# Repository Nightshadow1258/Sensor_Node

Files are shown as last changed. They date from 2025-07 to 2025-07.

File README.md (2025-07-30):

# Sensor Node Version 3.50
This is an intermediate version before I decided to move to a two part design.
I split the MCU Board into its own small form factor PCB with connectors on the bottom side to connect to a base board. The inspiration comes from the raspberry compute module. This will allow me to reuse the MCU for different design in the future.

## Components
- NRF52840 (MCU)
- NPM1300 (PMIC)
- BQ29700 (Battery Protection IC)
- SHT40 (Temp & Humidity Sensor)
- USB (charging & data transfer)

# Archive Notice

This repository has been archived and is no longer maintained.
It contains historical versions of the Sensor Node project (V1.00, V2.00, etc.)
for reference and backup purposes.

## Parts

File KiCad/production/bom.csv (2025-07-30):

Designator | Footprint | Quantity | Value | LCSC Part #
AE201 | Texas_SWRA117D_2.4GHz_Right | 1 | Antenna_Shield
C201, C205 | 0402 | 2 | 12pF | C1547
C202 | 0402 | 1 | 10nF | C15195
C203, C215 | 0402 | 2 | 1uF | C15525
C204, C219, C305, C306, C308 | 0603 | 5 | 10uF | C96446
C206, C207, C208, C212, C214, C217, C218, C220, C221, C301, C304 | 0402 | 11 | 100nF | C1525
C209 | 0402 | 1 | 0.8pF | C327032
C210, C211 | 0402 | 2 | 0.5pF | C285052
C213 | 0402 | 1 | 1.2pF
C216 | 0402 | 1 | 100pF | C1546
C302, C303, C307, C309 | 0402 | 4 | 1uF | C52923
CON101 | CON-GEN-USB_C-16P | 1 | G Switch GT USB 7010ASV | C2988369
CON102, CON103 | CON-SM02B-ZESS_TB | 2 | SM02B-ZESS-TB
CON201 | CON-TAG-CONNECT_TC2050-IDC | 1 | TC2050-FP
D101 | SOT-23-6 | 1 | USBLC6-2 | C7519
D201 | 0603 | 1 | BLUE | C72041
D301 | 0603 | 1 | GREEN | C72043
D302 | 0603 | 1 | RED | C2286
FID101, FID102, FID103, FID104 | Fiducal-JLCPCB | 4 | Fiducal-JLCPPCB
IC201 | Nordic_AQFN-73-1EP_7x7mm_P0.5mm | 1 | NRF52840 | C190794
IC202 | DNF-1.5x1.5_H0.54-SHT40-AD1B_THPAD | 1 | IC_SENS-SHT40-AD1B_THP
IC301 | WSON-6_1.5x1.5mm_P0.5mm | 1 | IC_PWREG-BQ29700 | C183096
IC302 | QFN-32-1EP_5x5mm_P0.5mm_EP3.6x3.6mm_ThermalVias | 1 | IC_PWREG-NPM1300
J201 | PinHeader_2x03_P2.54mm_Vertical | 1 | Conn_02x03_Odd_Even
L201 | 0402 | 1 | 4.7nH | C370227
L301 | L_0806 | 1 | 2.2uH | C2838367
MH101, MH102, MH103, MH104 | MountingHole_2.5mm_Pad_Via | 4 | ~
PCB101, PCB102, PCB103, PCB104 | PCB-NPTH-JLCPCB | 4 | Tooling Hole JLCPCB
R201 | 0402 | 1 | 1k | C11702
R202, R209, R301 | 0402 | 3 | 10k | C25744
R203, R205, R210 | 0402 | 3 | 1M | C138033
R204, R206, R207, R208 | 0402 | 4 | 4k7 | C25900
R211 | 0402 | 1 | 750k | C137937
R302 | 0402 | 1 | 2k | C4109
R303 | 0402 | 1 | 330 | C25104
R304 | 0402 | 1 | 200k | C25764
R305 | 0402 | 1 | 0 | C17168
R306 | 0603 | 1 | 10k | C142556
SW201, SW202 | SW-PUSH-DPST-XKS-TS-1187A | 2 | SW-GEN-TS-1187A | C318884
T301 | SOT-23 | 1 | SI2312BDS | C351405
T302 | SOT-23-6 | 1 | DMG6968UDM | C2762931
TP201, TP202, TP203, TP204, TP205, TP301, TP302, TP307, TP308, TP311, TP313, TP314 | TP_Pad_D0.9mm | 12 | TP
TP304, TP309, TP310 | TP_THT_D0.8mm | 3 | Testpoint-BASE
X201 | Crystal_SMD_3225-4Pin_3.2x2.5mm | 1 | 32MHz | C2901708

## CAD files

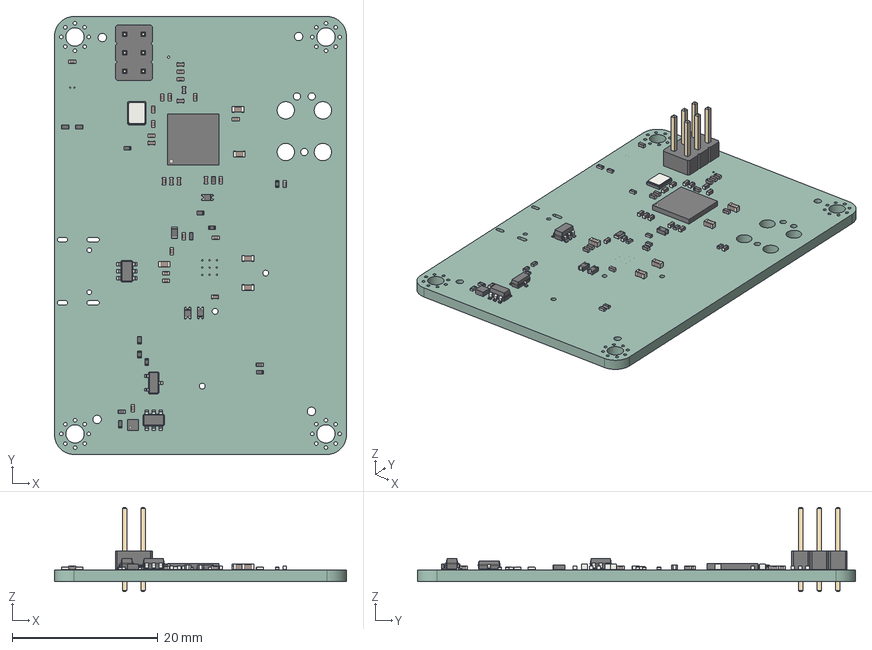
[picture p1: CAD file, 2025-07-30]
KiCad/Sensor_Nodes.step
40.0 x 60.0 x 11.5 mm
C_0402_1005Metric x 26
SOT_23_6 x 2
L_0402_1005Metric
R_0402_1005Metric x 15
Nordic_AQFN-73-1EP_7x7mm_P0.5mm
SOT_23
C_0603_1608Metric x 5
R_0603_1608Metric
WSON6_15x15mm_Pitch05mm
D_0603 x 3
Crystal_SMD_3225-4Pin_3.2x2.5mm
PinHeader_2x03_P254mm_Vertical
Sensor_Nodes_PCB

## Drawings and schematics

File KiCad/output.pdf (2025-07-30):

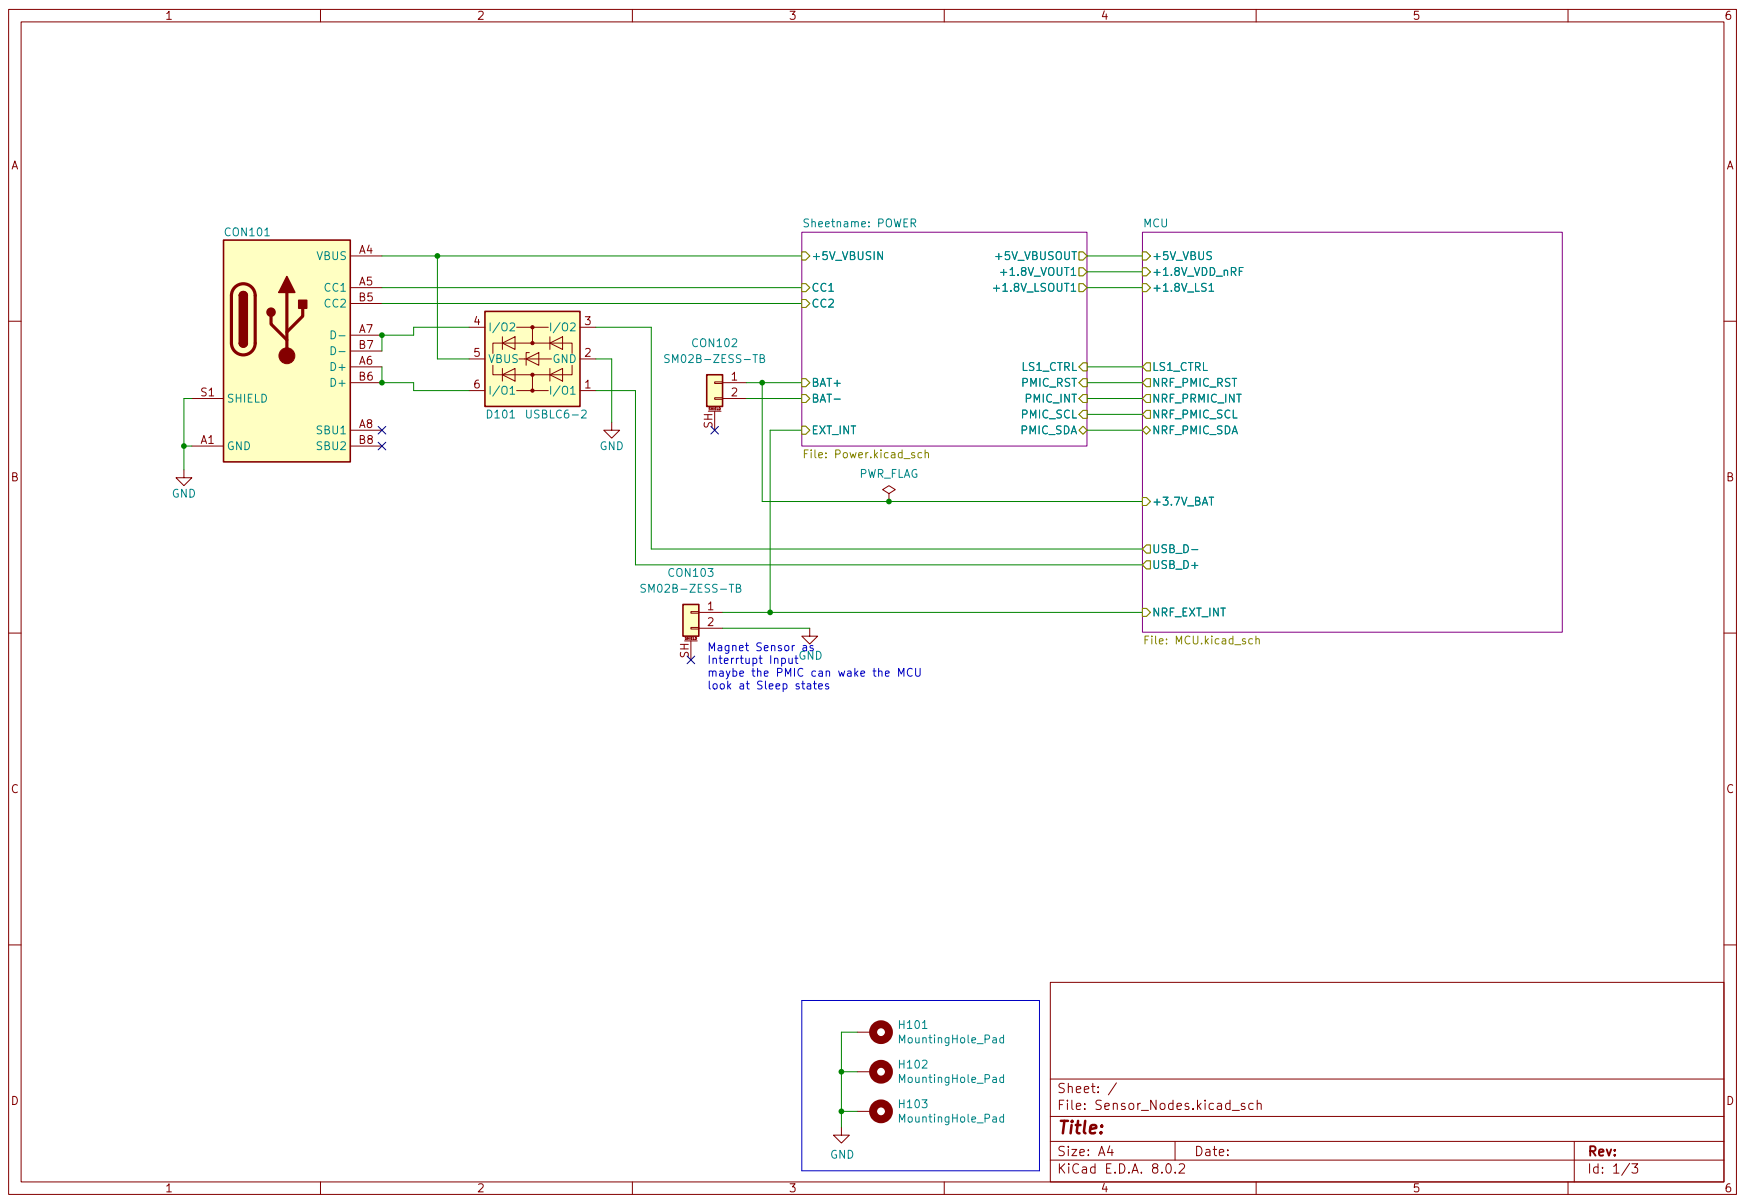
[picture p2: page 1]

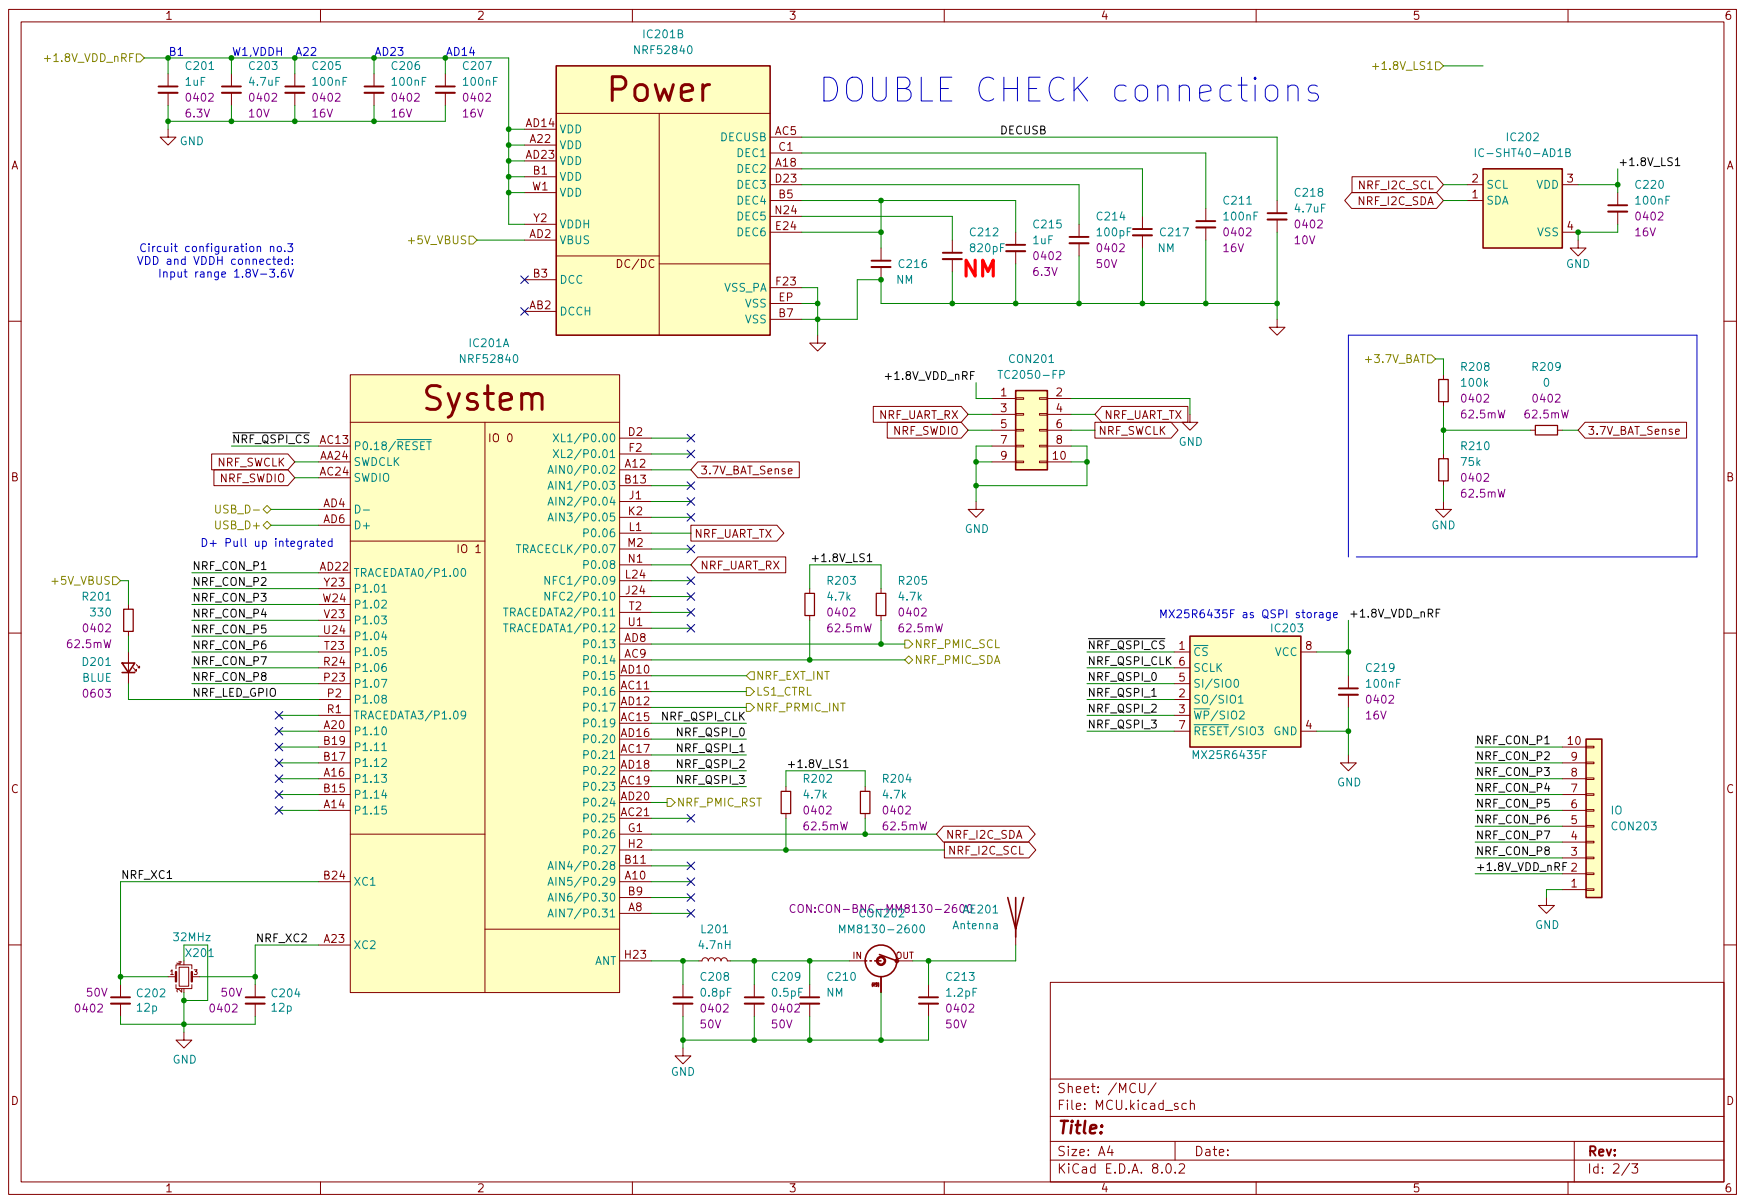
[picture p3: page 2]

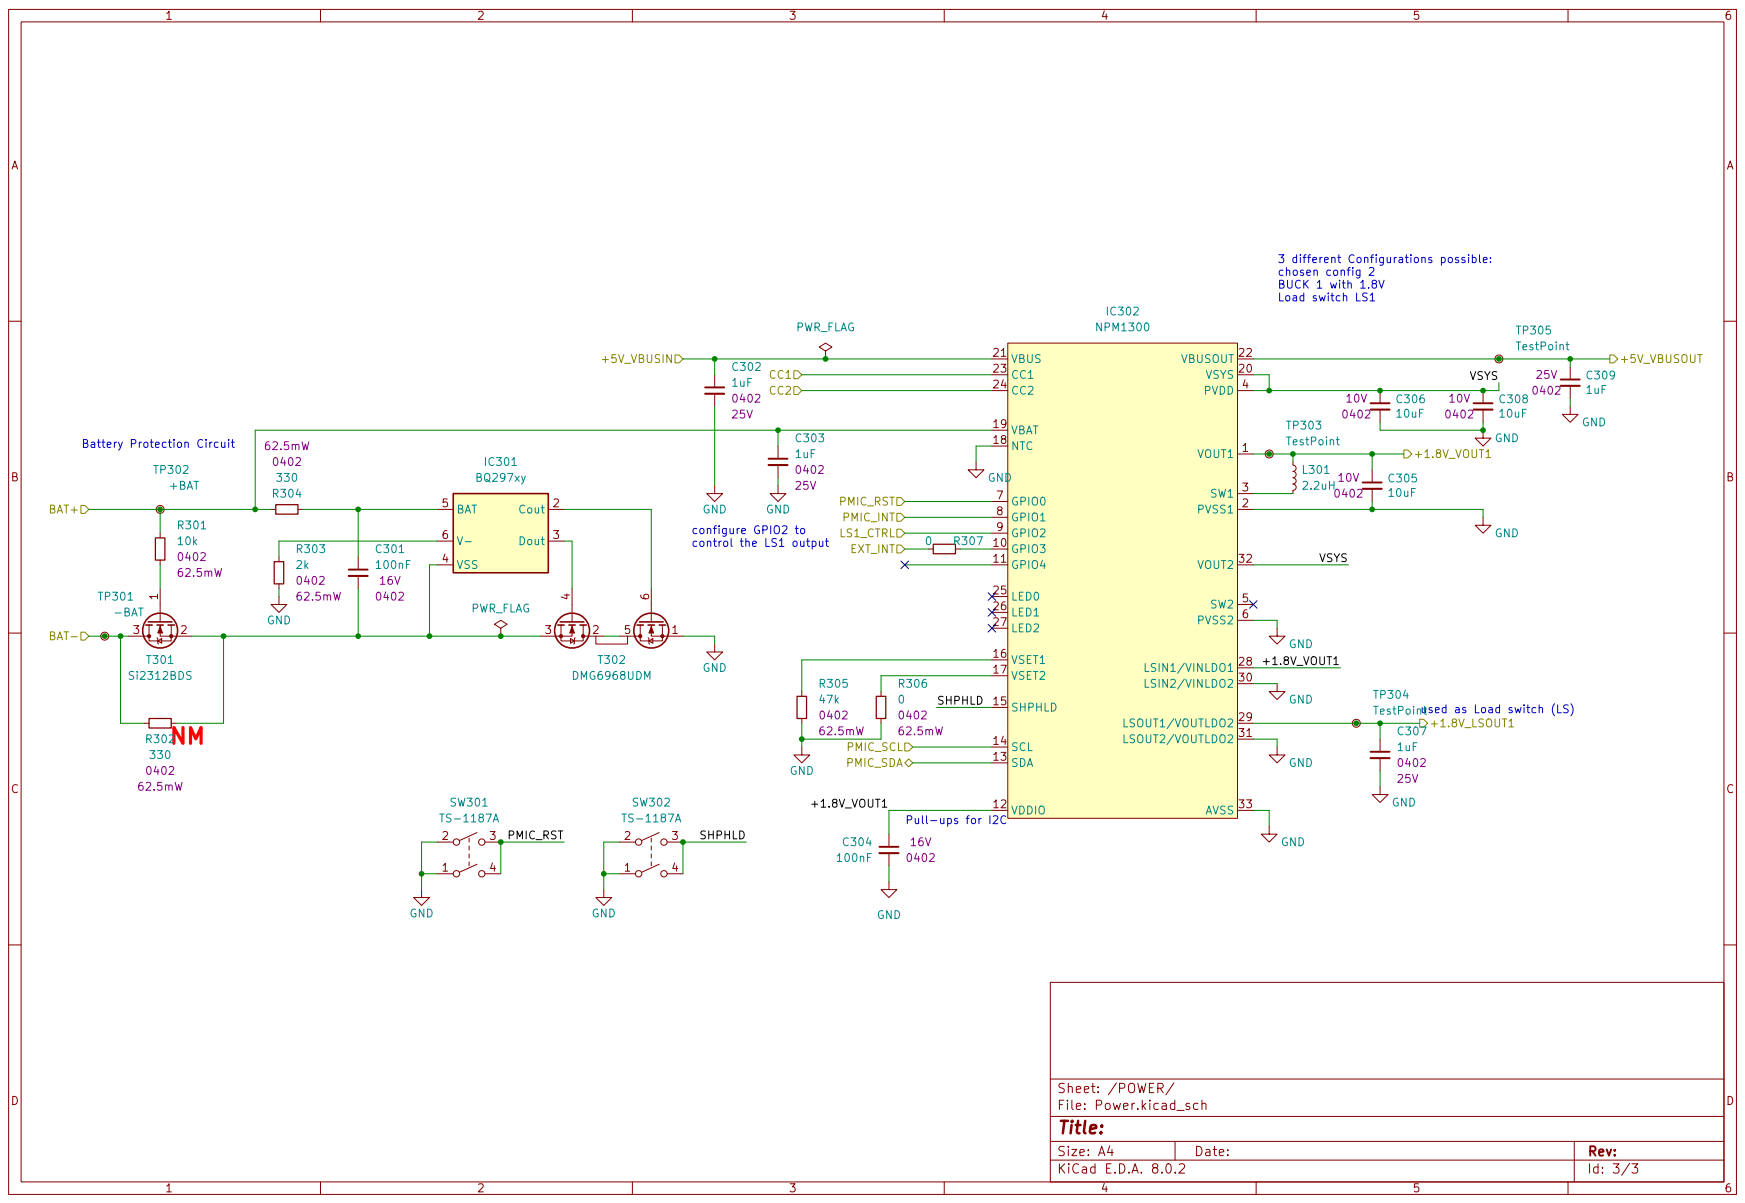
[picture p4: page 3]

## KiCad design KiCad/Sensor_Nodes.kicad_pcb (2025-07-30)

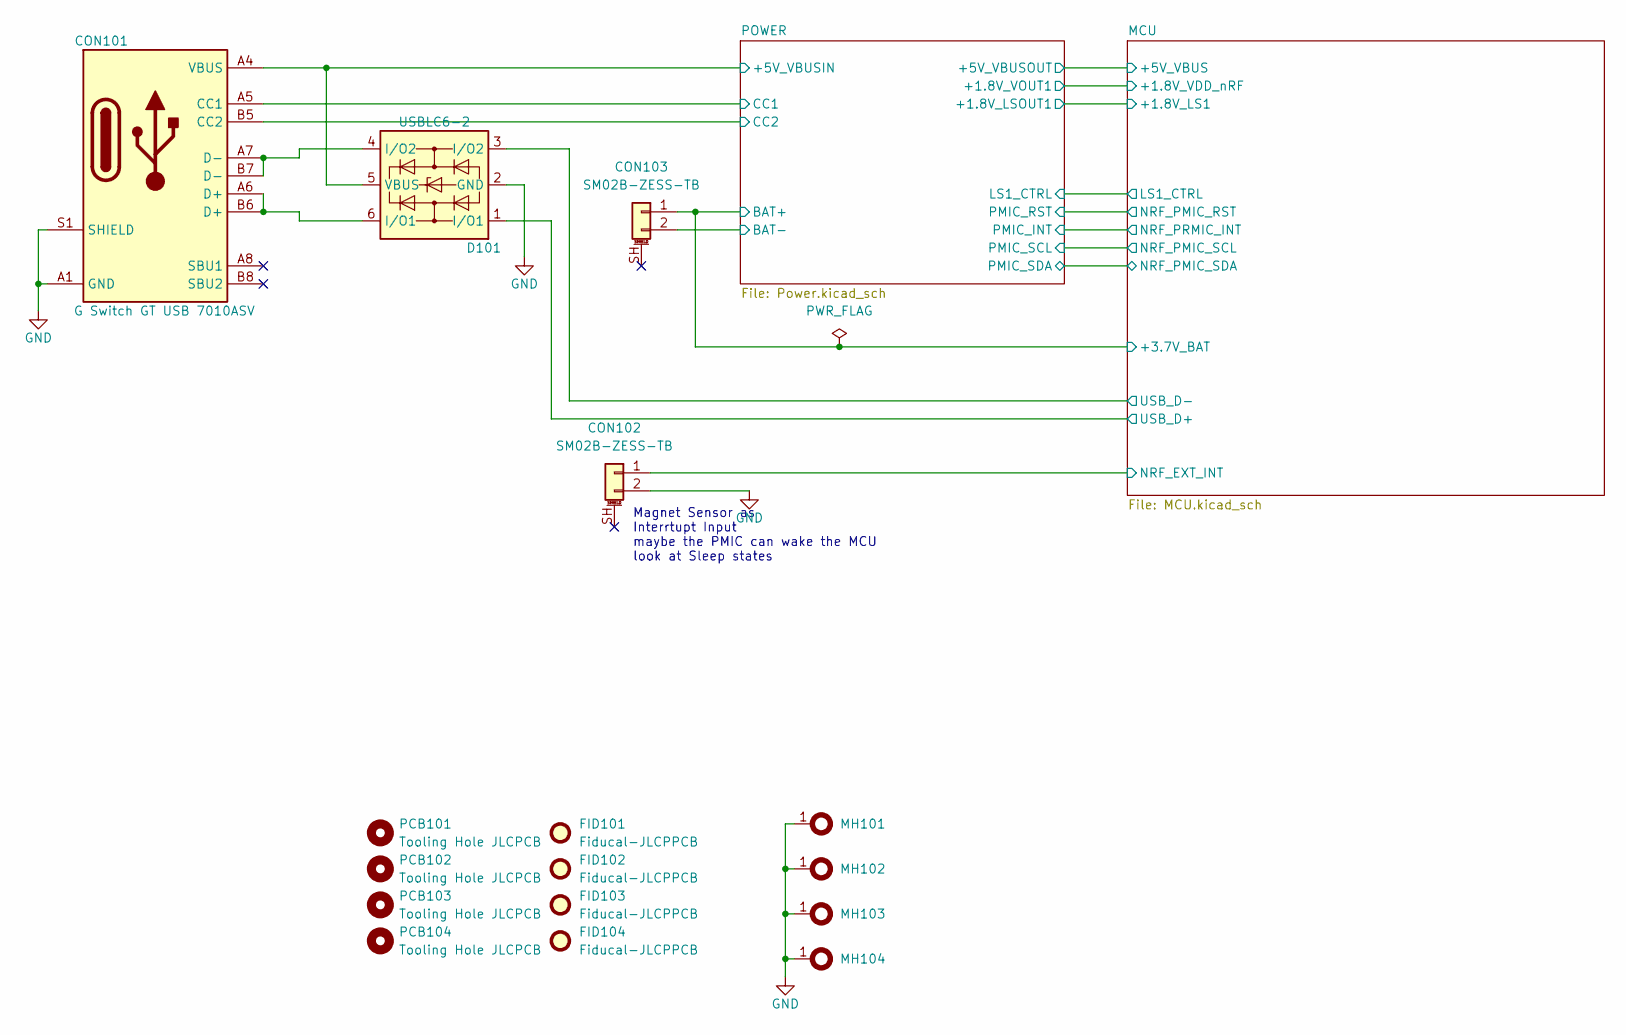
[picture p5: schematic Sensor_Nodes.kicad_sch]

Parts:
CON101: G Switch GT USB 7010ASV; CON-GEN-USB_C-16P; LCSC Part # C2988369
CON102, CON103: SM02B-ZESS-TB; CON-SM02B-ZESS_TB
D101: USBLC6-2; SOT-23-6; LCSC Part # C7519
FID101, FID102, FID103, FID104: Fiducal-JLCPPCB; Fiducal-JLCPCB
MH101, MH102, MH103, MH104: MountingHole_2.5mm_Pad_Via
PCB101, PCB102, PCB103, PCB104: Tooling Hole JLCPCB; PCB-NPTH-JLCPCB

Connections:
/MCU/+3.7V_BAT: CON103.1; also elsewhere on the board
/MCU/NRF_EXT_INT: CON102.1; also elsewhere on the board
/MCU/USB_D+: D101.1 (I/O1); also elsewhere on the board
/MCU/USB_D-: D101.3 (I/O2); also elsewhere on the board
/POWER/+5V_VBUSIN: CON101.A4 (VBUS), CON101.A9 (VBUS), CON101.B4 (VBUS), CON101.B9 (VBUS), D101.5 (VBUS); also elsewhere on the board
/POWER/BAT-: CON103.2; also elsewhere on the board
/POWER/CC1: CON101.A5 (CC1); also elsewhere on the board
/POWER/CC2: CON101.B5 (CC2); also elsewhere on the board
GND: CON101.A1 (GND), CON101.A12 (GND), CON101.B1 (GND), CON101.B12 (GND), CON101.S1 (SHIELD), CON102.2, D101.2 (GND), MH101.1, MH102.1, MH103.1, MH104.1; also elsewhere on the board
unnamed: CON101.A6 (D+), CON101.B6 (D+), D101.6 (I/O1)
unnamed: CON101.A7 (D-), CON101.B7 (D-), D101.4 (I/O2)

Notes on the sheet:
Magnet Sensor as Interrtupt Input maybe the PMIC can wake the MCU look at Sleep states

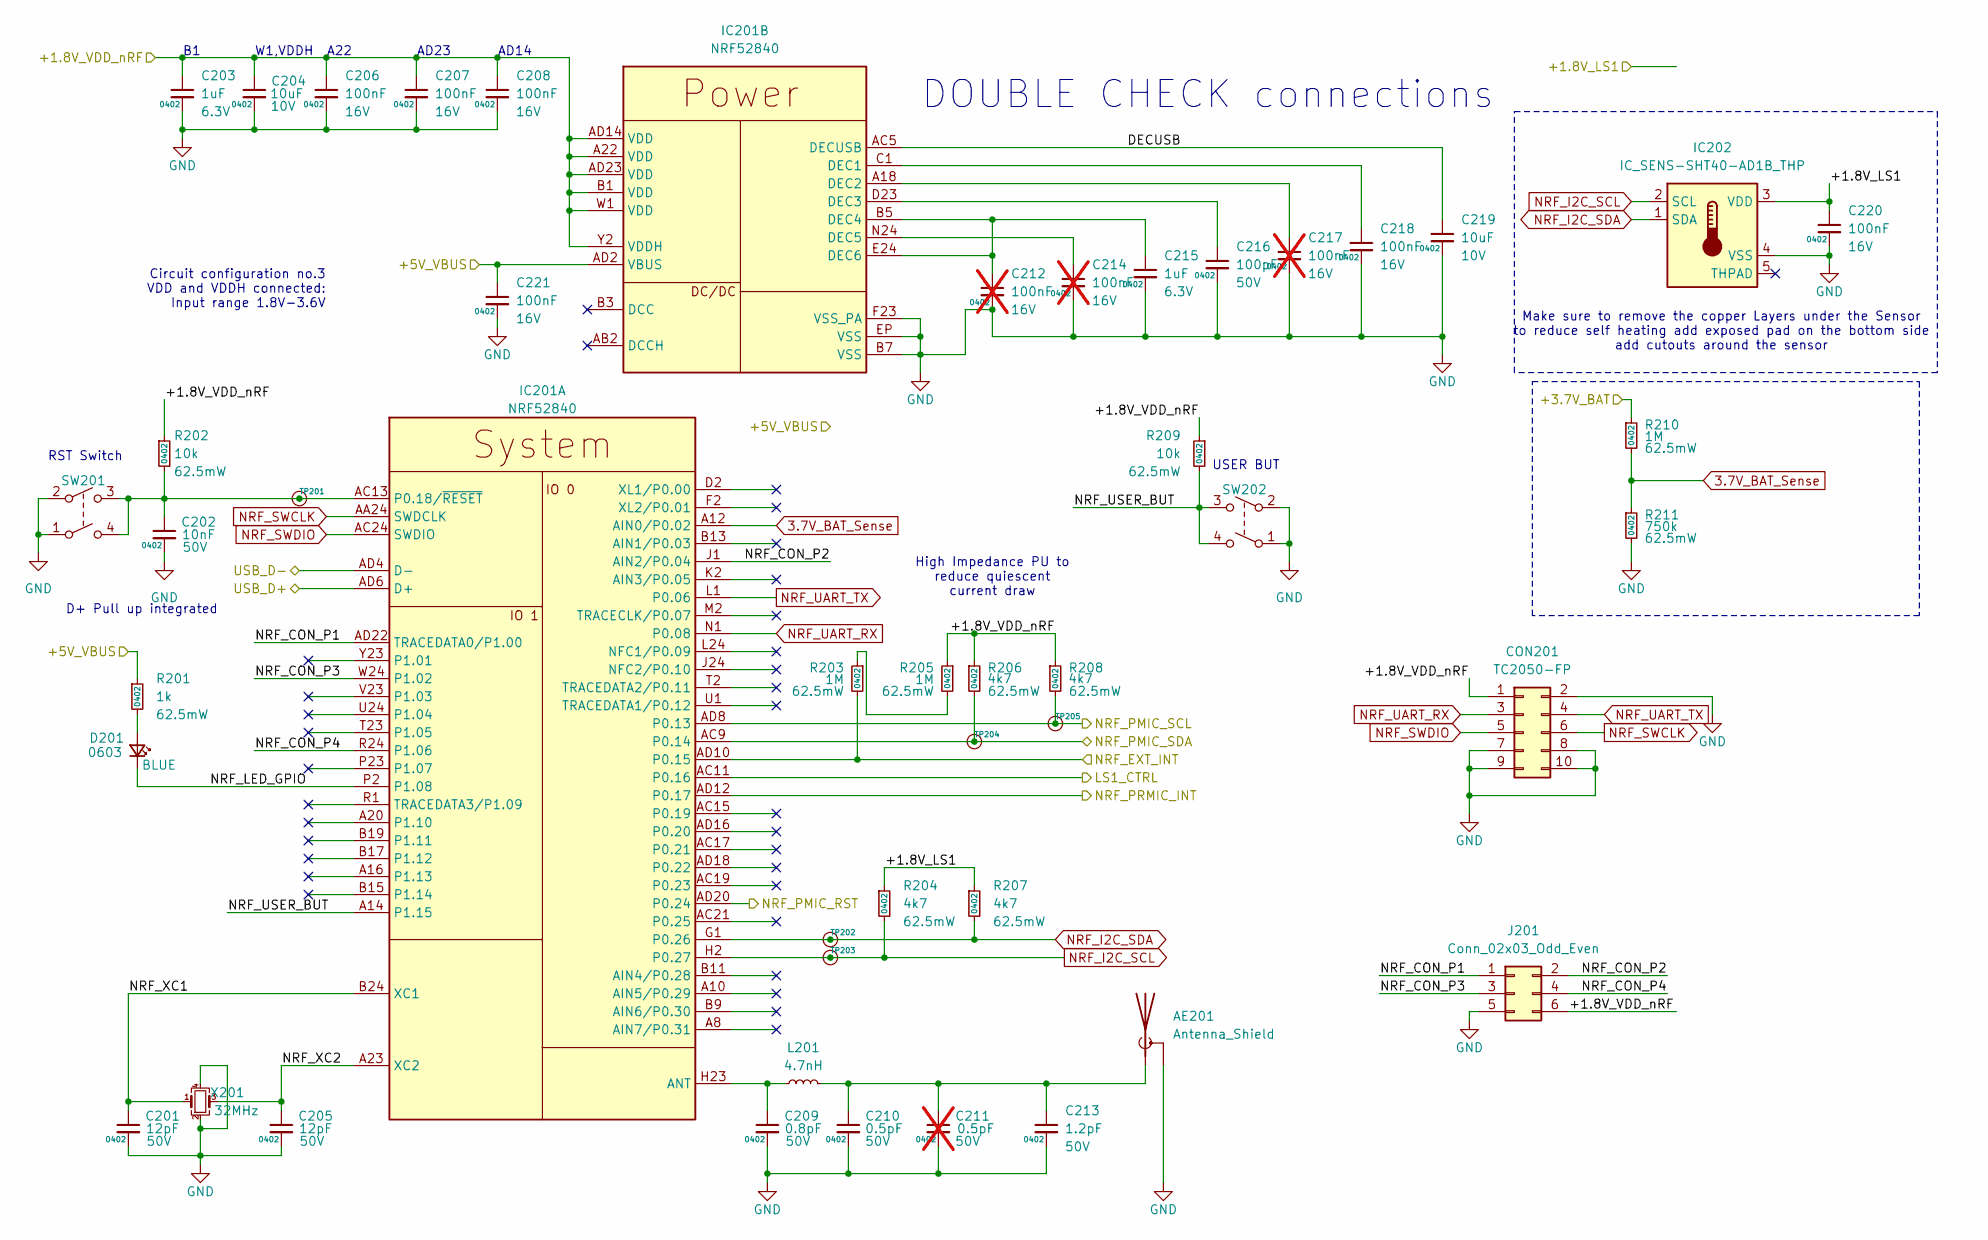
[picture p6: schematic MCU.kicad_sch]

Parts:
AE201: Antenna_Shield; Texas_SWRA117D_2.4GHz_Right
C201, C205: 12pF; C_0402_1005Metric; Voltage 50V; LCSC Part # C1547
C202: 10nF; C_0402_1005Metric; Voltage 50V; LCSC Part # C15195
C203, C215: 1uF; C_0402_1005Metric; Voltage 6.3V; LCSC Part # C15525
C204, C219: 10uF; C_0603_1608Metric; Voltage 10V; LCSC Part # C96446
C206, C207, C208, C218, C220, C221: 100nF; C_0402_1005Metric; Voltage 16V; LCSC Part # C1525
C209: 0.8pF; C_0402_1005Metric; Voltage 50V; LCSC Part # C327032
C210: 0.5pF; C_0402_1005Metric; Voltage 50V; LCSC Part # C285052
C211: 0.5pF; C_0402_1005Metric; Voltage 50V; LCSC Part # C285052; not fitted
C212, C214, C217: 100nF; C_0402_1005Metric; Voltage 16V; LCSC Part # C1525; not fitted
C213: 1.2pF; C_0402_1005Metric; Voltage 50V; LCSC Part #q C1551
C216: 100pF; C_0402_1005Metric; Voltage 50V; LCSC Part # C1546
CON201: TC2050-FP; CON-TAG-CONNECT_TC2050-IDC
D201: BLUE; D_0603_1608Metric; LCSC Part # C72041
IC201: NRF52840; Nordic_AQFN-73-1EP_7x7mm_P0.5mm; LCSC Part # C190794
IC202: IC_SENS-SHT40-AD1B_THP; DNF-1.5x1.5_H0.54-SHT40-AD1B_THPAD
J201: Conn_02x03_Odd_Even; PinHeader_2x03_P2.54mm_Vertical
L201: 4.7nH; L_0402_1005Metric; LCSC Part # C370227
R201: 1k; R_0402_1005Metric; Power Rating 62.5mW; LCSC Part # C11702
R202, R209: 10k; R_0402_1005Metric; Power Rating 62.5mW; LCSC Part # C25744
R203, R205, R210: 1M; R_0402_1005Metric; Power Rating 62.5mW; LCSC Part # C138033
R204, R206, R207, R208: 4k7; R_0402_1005Metric; Power Rating 62.5mW; LCSC Part # C25900
R211: 750k; R_0402_1005Metric; Power Rating 62.5mW; LCSC Part # C137937
SW201, SW202: SW-GEN-TS-1187A; SW-PUSH-DPST-XKS-TS-1187A; LCSC Part # C318884
TP201, TP202, TP203, TP204, TP205: TP; TP_Pad_D0.9mm
X201: 32MHz; Crystal_SMD_3225-4Pin_3.2x2.5mm; LCSC Part # C2901708

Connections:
3.7V_BAT_Sense: IC201.A12 (AIN0/P0.02), R210.2, R211.1
/MCU/+1.8V_LS1: C220.1, IC202.3 (VDD), R204.1, R207.1; also elsewhere on the board
/MCU/+1.8V_VDD_nRF: C203.1, C204.1, C206.1, C207.1, C208.1, CON201.1, IC201.A22 (VDD), IC201.AD14 (VDD), IC201.AD23 (VDD), IC201.B1 (VDD), IC201.W1 (VDD), IC201.Y2 (VDDH), J201.6, R202.1, R205.1, R206.1, R208.1, R209.1; also elsewhere on the board
/MCU/+3.7V_BAT: R210.1; also elsewhere on the board
/MCU/+5V_VBUS: C221.1, IC201.AD2 (VBUS), R201.1; also elsewhere on the board
/MCU/DECUSB: C219.1, IC201.AC5 (DECUSB)
/MCU/LS1_CTRL: IC201.AC11 (P0.16); also elsewhere on the board
/MCU/NRF_CON_P1: IC201.AD22 (TRACEDATA0/P1.00), J201.1
/MCU/NRF_CON_P2: IC201.J1 (AIN2/P0.04), J201.2
/MCU/NRF_CON_P3: IC201.W24 (P1.02), J201.3
/MCU/NRF_CON_P4: IC201.R24 (P1.06), J201.4
/MCU/NRF_EXT_INT: IC201.AD10 (P0.15), R203.2; also elsewhere on the board
/MCU/NRF_LED_GPIO: D201.1 (K), IC201.P2 (P1.08)
/MCU/NRF_PMIC_RST: IC201.AD20 (P0.24); also elsewhere on the board
/MCU/NRF_PMIC_SCL: IC201.AD8 (P0.13), R208.2, TP205.1; also elsewhere on the board
/MCU/NRF_PMIC_SDA: IC201.AC9 (P0.14), R206.2, TP204.1; also elsewhere on the board
/MCU/NRF_PRMIC_INT: IC201.AD12 (P0.17); also elsewhere on the board
/MCU/NRF_USER_BUT: IC201.A14 (P1.15), R209.2, SW202.3 (4), SW202.4
/MCU/NRF_XC1: C201.1, IC201.B24 (XC1), X201.1
/MCU/NRF_XC2: C205.1, IC201.A23 (XC2), X201.3
/MCU/USB_D+: IC201.AD6 (D+); also elsewhere on the board
/MCU/USB_D-: IC201.AD4 (D-); also elsewhere on the board
GND: AE201.2 (Shield), C201.2, C202.2, C203.2, C204.2, C205.2, C206.2, C207.2, C208.2, C209.2, C210.2, C211.2, C212.2, C213.2, C214.2, C215.2, C216.2, C217.2, C218.2, C219.2, C220.2, C221.2, CON201.2, CON201.7, CON201.8, CON201.9, CON201.10, IC201.B7 (VSS), IC201.EP (VSS), IC201.F23 (VSS_PA), IC202.4 (VSS), J201.5, R211.2, SW201.1, SW201.2 (3), SW202.1, SW202.2 (3), X201.2, X201.4; also elsewhere on the board
NRF_I2C_SCL: IC201.H2 (P0.27), IC202.2 (SCL), R204.2, TP203.1
NRF_I2C_SDA: IC201.G1 (P0.26), IC202.1 (SDA), R207.2, TP202.1
NRF_SWCLK: CON201.6, IC201.AA24 (SWDCLK)
NRF_SWDIO: CON201.5, IC201.AC24 (SWDIO)
NRF_UART_RX: CON201.3, IC201.N1 (P0.08)
NRF_UART_TX: CON201.4, IC201.L1 (P0.06)
unnamed: AE201.1 (A), C210.1, C211.1, C213.1, L201.2
unnamed: D201.2 (A), R201.2
unnamed: C209.1, IC201.H23 (ANT), L201.1
unnamed: C202.1, IC201.AC13 (P0.18/~RESET), R202.2, SW201.3 (4), SW201.4, TP201.1
unnamed: C218.1, IC201.C1 (DEC1)
unnamed: C217.1, IC201.A18 (DEC2)
unnamed: C216.1, IC201.D23 (DEC3)
unnamed: C212.1, C215.1, IC201.B5 (DEC4), IC201.E24 (DEC6)
unnamed: C214.1, IC201.N24 (DEC5)
unnamed: R203.1, R205.2

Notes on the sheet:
AD23
Circuit configuration no.3 VDD and VDDH connected: Input range 1.8V-3.6V
DOUBLE CHECK connections
USER BUT
A22
High Impedance PU to reduce quiescent current draw
AD14
Make sure to remove the copper Layers under the Sensor to reduce self heating add exposed pad on the bottom side add cutouts around the sensor
W1,VDDH
RST Switch
D+ Pull up integrated

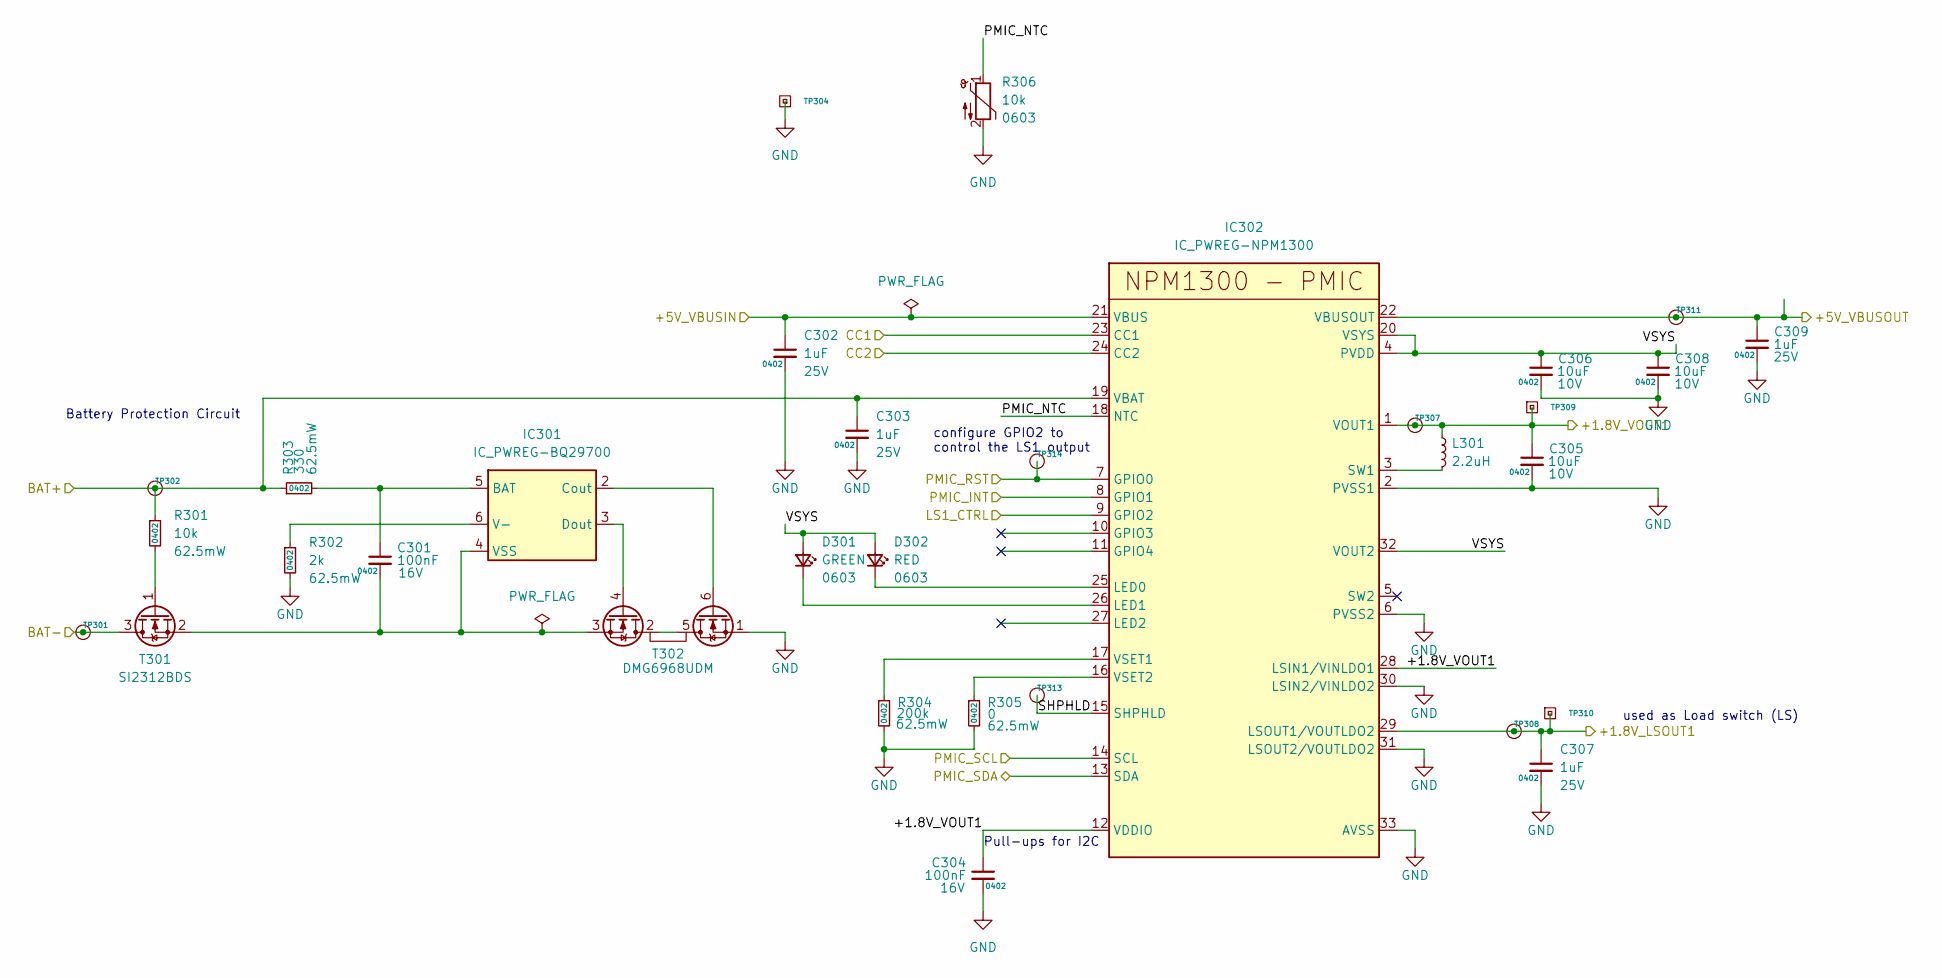
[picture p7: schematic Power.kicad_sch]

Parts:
C301, C304: 100nF; C_0402_1005Metric; Voltage 16V; LCSC Part # C1525
C302, C303, C307, C309: 1uF; C_0402_1005Metric; Voltage 25V; LCSC Part # C52923
C305, C306, C308: 10uF; C_0603_1608Metric; Voltage 10V; LCSC Part # C96446
D301: GREEN; D_0603_1608Metric; LCSC Part # C72043
D302: RED; D_0603_1608Metric; LCSC Part # C2286
IC301: IC_PWREG-BQ29700; WSON-6_1.5x1.5mm_P0.5mm; LCSC Part # C183096
IC302: IC_PWREG-NPM1300; QFN-32-1EP_5x5mm_P0.5mm_EP3.6x3.6mm_ThermalVias
L301: 2.2uH; L_0806; LCSC Part # C2838367
R301: 10k; R_0402_1005Metric; Power Rating 62.5mW; LCSC Part # C25744
R302: 2k; R_0402_1005Metric; Power Rating 62.5mW; LCSC Part # C4109
R303: 330; R_0402_1005Metric; Power Rating 62.5mW; LCSC Part # C25104
R304: 200k; C_0402_1005Metric; Power Rating 62.5mW; LCSC Part # C25764
R305: 0; R_0402_1005Metric; Power Rating 62.5mW; LCSC Part # C17168
R306: 10k; R_0603_1608Metric; LCSC Part # C142556
T301: SI2312BDS; SOT-23; LCSC Part # C351405
T302: DMG6968UDM; SOT-23-6; LCSC Part # C2762931
TP301, TP302, TP307, TP308, TP311, TP313, TP314: TP; TP_Pad_D0.9mm
TP304, TP309, TP310: Testpoint-BASE; TP_THT_D0.8mm

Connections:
/MCU/+1.8V_LS1: C307.1, IC302.29 (LSOUT1/VOUTLDO2), TP308.1, TP310.1; also elsewhere on the board
/MCU/+1.8V_VDD_nRF: C304.1, C305.1, IC302.1 (VOUT1), IC302.12 (VDDIO), IC302.28 (LSIN1/VINLDO1), L301.1, TP307.1, TP309.1; also elsewhere on the board
/MCU/+3.7V_BAT: C303.1, IC302.19 (VBAT), R301.1, R303.1, TP302.1; also elsewhere on the board
/MCU/+5V_VBUS: C309.1, IC302.22 (VBUSOUT), TP311.1; also elsewhere on the board
/MCU/LS1_CTRL: IC302.9 (GPIO2); also elsewhere on the board
/MCU/NRF_PMIC_RST: IC302.7 (GPIO0), TP314.1; also elsewhere on the board
/MCU/NRF_PMIC_SCL: IC302.14 (SCL); also elsewhere on the board
/MCU/NRF_PMIC_SDA: IC302.13 (SDA); also elsewhere on the board
/MCU/NRF_PRMIC_INT: IC302.8 (GPIO1); also elsewhere on the board
/POWER/+5V_VBUSIN: C302.1, IC302.21 (VBUS); also elsewhere on the board
/POWER/BAT-: T301.3 (D), TP301.1; also elsewhere on the board
/POWER/CC1: IC302.23 (CC1); also elsewhere on the board
/POWER/CC2: IC302.24 (CC2); also elsewhere on the board
/POWER/PMIC_NTC: IC302.18 (NTC), R306.1
/POWER/SHPHLD: IC302.15 (SHPHLD), TP313.1
/POWER/VSYS: C306.1, C308.1, D301.2 (A), D302.2 (A), IC302.4 (PVDD), IC302.20 (VSYS), IC302.32 (VOUT2)
GND: C302.2, C303.2, C304.2, C305.2, C306.2, C307.2, C308.2, C309.2, IC302.2 (PVSS1), IC302.6 (PVSS2), IC302.30 (LSIN2/VINLDO2), IC302.31 (LSOUT2/VOUTLDO2), IC302.33 (AVSS), R302.2, R304.2, R305.2, R306.2, T302.1 (S1), TP304.1; also elsewhere on the board
unnamed: D301.1 (K), IC302.26 (LED1)
unnamed: D302.1 (K), IC302.25 (LED0)
unnamed: C301.1, IC301.5 (BAT), R303.2
unnamed: IC301.2 (Cout), T302.6 (G1)
unnamed: IC301.3 (Dout), T302.4 (G2)
unnamed: IC301.6 (V-), R302.1
unnamed: C301.2, IC301.4 (VSS), T301.2 (S), T302.3 (S2)
unnamed: IC302.3 (SW1), L301.2
unnamed: IC302.17 (VSET1), R304.1
unnamed: IC302.16 (VSET2), R305.1
unnamed: R301.2, T301.1 (G)
unnamed: T302.2 (D1/D2), T302.5 (D1/D2)

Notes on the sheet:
Pull-ups for I2C
Battery Protection Circuit
configure GPIO2 to control the LS1 output
used as Load switch (LS)

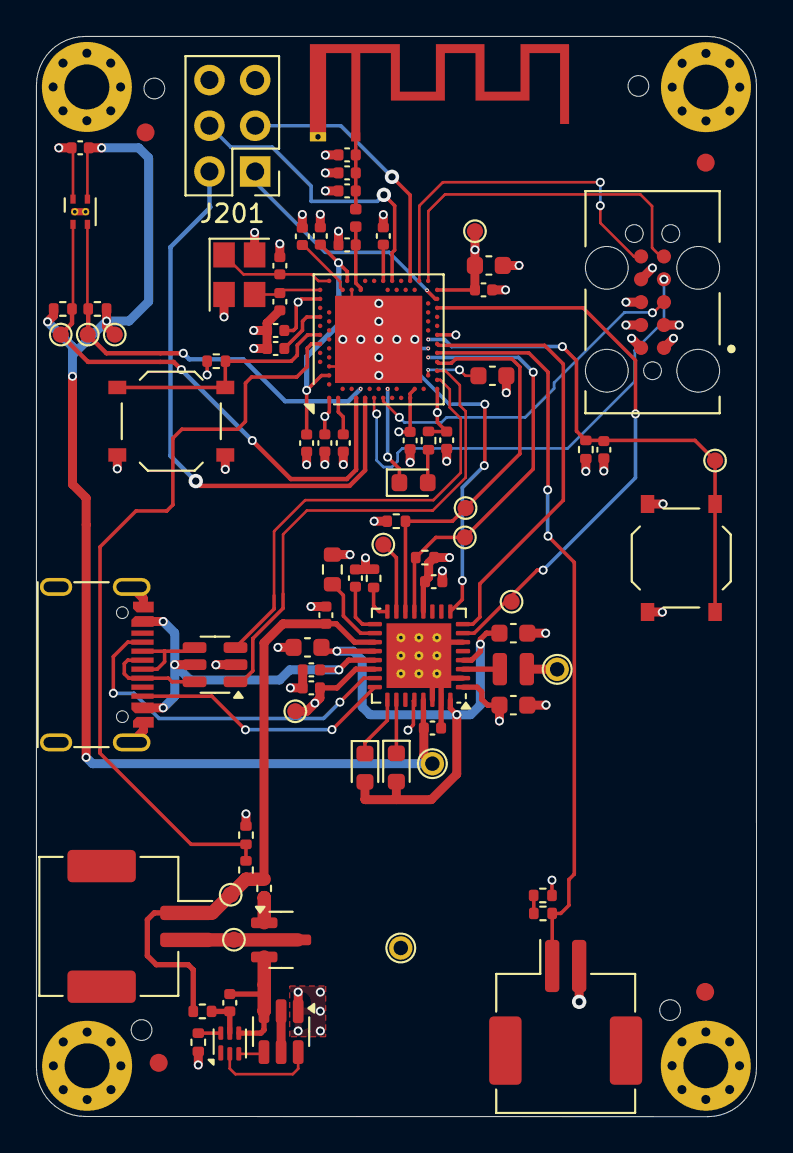
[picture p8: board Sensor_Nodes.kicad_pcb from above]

Board: 4 copper layers, 40.0 x 60.0 mm, 95 parts (0 on the bottom side), 60 nets.
